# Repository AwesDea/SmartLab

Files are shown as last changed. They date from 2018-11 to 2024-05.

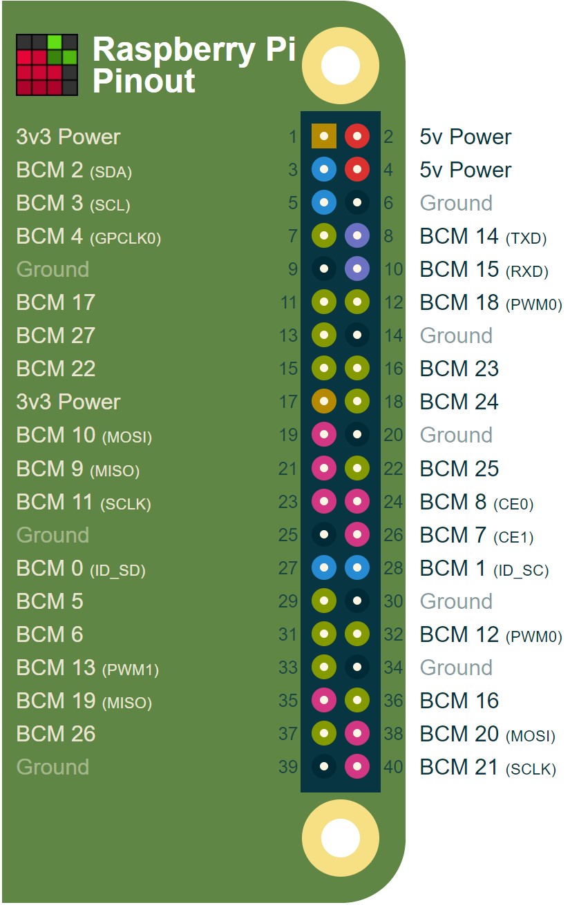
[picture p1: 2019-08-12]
Document/Pic/RPi3 Pinout.jpg

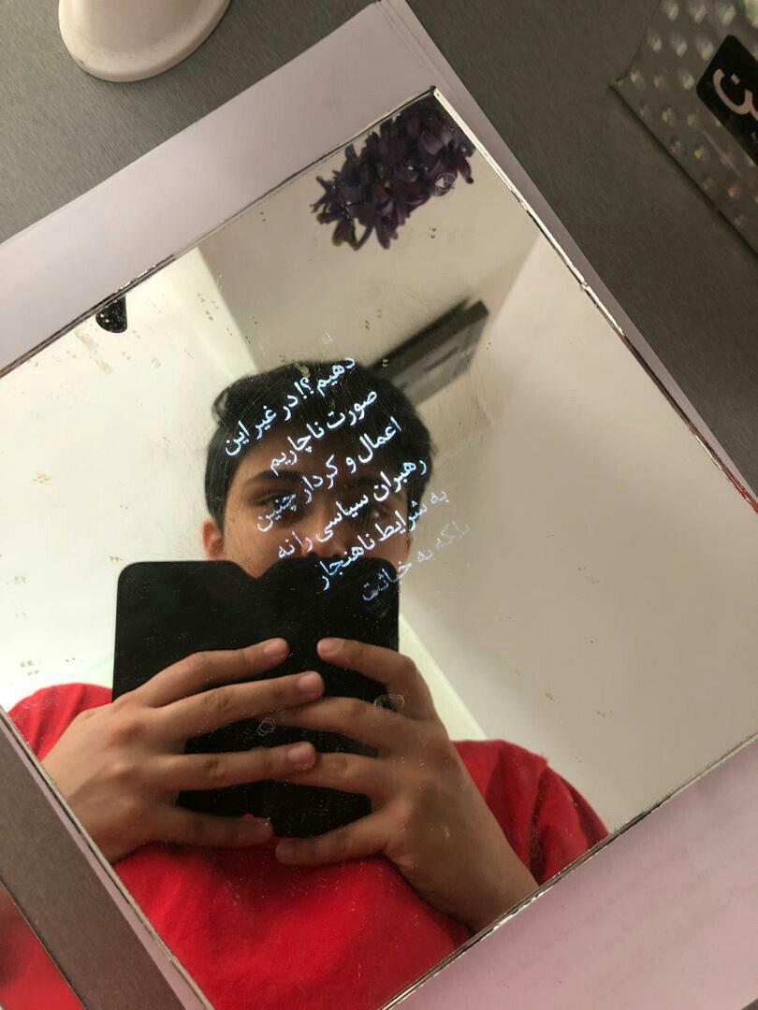
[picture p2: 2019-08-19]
Document/Pic/SMir- Test.jpg

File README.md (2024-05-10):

# Smart Lab with Raspberry Pi and Esp8266

One RaspberryPi, three ESP8266s, a bunch of sensors and data to keep and use it later.

## Built With

* [Python3](https://python.org) - RaspberryPi code
* [Pandas](https://pandas.pydata.org/) - Data Management
* [Arduino Editor](https://www.arduino.cc/) - Used to code and program ESP8266

## Authors

* **Hoorad Abootalebi** - *Most of Hardware work* - [Hoora](https://github.com/HooradAboo)
* **Amin Isaai** - *Most of Software work* - [Amin](https://github.com/HooraAboo)

See also the list of [contributors](https://github.com/your/project/contributors) who participated in this project.

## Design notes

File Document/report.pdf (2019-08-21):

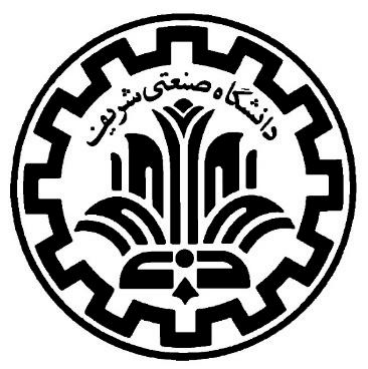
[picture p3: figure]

دانشگاه صنعتی شریف
دانشکدهی مهندسیکامپیوتر

پایاننامهی کارشناسی

عنوان:

## پیاده سازی اتاق هوشمند

نگارش:
فاطمه ابوطالبی، محمد امین عیسایی

استاد راهنما:

علی محمد افشین همتیار

سال تحصیلی ۱۳۹۸-۹۷

به نام خدا
دانشگاه صنعتی شریف
دانشکده مهندسی کامپیوتر

پایان نامه کارشناسی

عنوان: پیادهسازی اتاق هوشمند

نگارش: فاطمه ابوطالبی، محمدامین عیسایی

کمیتهی ممتحنین

استاد راهنما: علی محمد افشین همتیار امضا: تاریخ:

## سپاس

از استاد بزرگوارمان که با کمکها و راهنماییهای بیدریغشان ما را در انجام این پروژه یاری دادهاند، تشکر و قدردانی میکنیم. همچنین از آقای مهندس بهنام بحیرایی که در پیشبرد این مقاله همکاری داشتند، صمیمانه سپاسگزاریم.

## چکیده

با پیشرفت روزافزون تکنولوژی و گسترش حوزهی اینترنت اشیا به منظور ایجاد سهولت در زندگی روزمره، تصمیم گرفتیم با هوشمندسازی محل کار در قسمتی از این پروژهی جهانی سهیم باشیم.

محل کار از بخشهای مختلفی تشکیل میشود که قابلیت هوشمندسازی را دارند. با استفاده از قابلیتها و کمک گرفتن از پروتکلهای ارتباطی از جمله MQTT و دیگر پروتکلهای ارتباطی از راه دور و هم چنین سنسورهای مختلف موجود در بازار تالش خواهیم کرد تا به پیادهسازی محل کاری هوشمند نزدیک شویم و در نهایت بتوانیم محیطی مدرن و پویاتر برای کار ایجاد کنیم و آسایش را برای افراد به ارمغان بیاوریم.

این پروژه در بستر B Model 3 Pi Raspberry انجام میشود. Pi Raspberry
مینیکامپیوتری است دارای چهل پایه، متشکل از بیست و هشت پایهی GPIO و هشت پایهی اتصال به زمین و چهار پایهی VCC است. Pi Raspberry ماژولهای ارتباطی مثل بلوتوث و وایفای، اترنت و ... را به صورت پیشفرض دارا است. همچنین از توزیع مخصوص سیستم عامل لینوکس رPi Raspberry، یعنی رزبین )Raspbian )استفاده خواهیم کرد.

در این پروژه قصد داریم با استفاده از Pi Raspberry و به کمک رابطهای کاربری به پیادهسازی محل کاری هوشمند بپردازیم.

کلید واژه: اینترنت هوشمند، خانهی هوشمند، اتاق هوشمند، IoT، MQTT، Pi Raspberry

## فهرست مطالب

۱5 | Raspberry Pi
24 | ESP8266
2۸ | Arduino
2۸ | Arduino Uno

42 | MQTT

## فهرست شکلها

۱6 | Raspberry Pi 3 Model B 2 شکل

## فهرست جدولها

# مقدمه

۱ | در این فصل در ابتدا تعریفی از اینترنت اشیا

ارائه میشود و سپس به بررسی ساختار، ویژگیها و کاربردهای آن میپردازیم.

## تعریف اینترنت اشیا

اینترنت اشیا شبکهای از دستگاههایی نظیر خودروها و لوازم خانگیای است که قطعات
2 و توانایی ارتباط۳ | الکترونیکی، نرمافزار، عملگرها
همراه خود دارند که به آنها توانایی تعامل و
تبادل داده میدهد ]۱[.

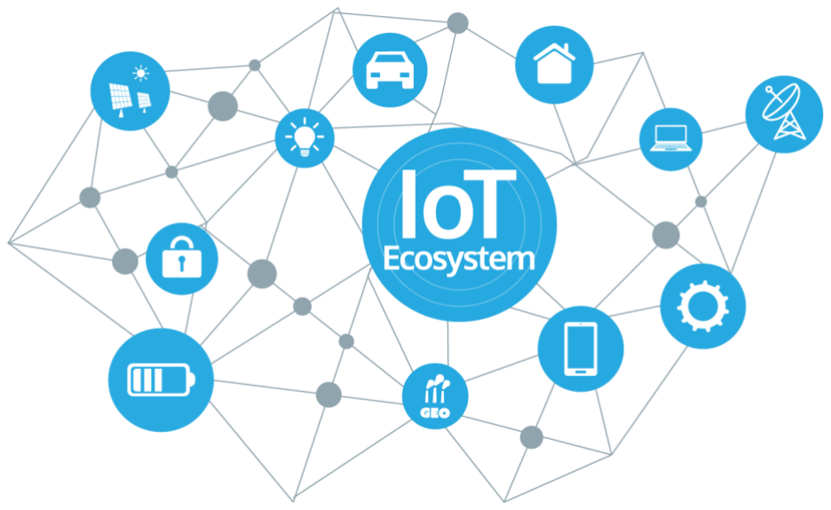
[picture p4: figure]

شکل ۱ اکوسیستم اینترنت اشیا

۱

Internet of Things
2 Actuator

۳ Connectivity

## ساختار اینترنت اشیا

با نگاهی ساده ساختار اینترنت اشیا از سه الیه تشکیل شده است. این سه الیه از قرار زیر هستند:

.۱ الیهی دستگاهها: در این الیه دستگاههایی همانند حسگرها و محرکها که با شبکه به یک
4 | دیگر متصلاند یافت میشوند. معموالً این دستگاهها از قراردادهایی
همچون Modbus و
Zigbee برای ارتباط با الیهی درگاه لبه استفاده میکنند. .2 الیهی درگاه لبه: این الیه از سامانههای جمعاوری دادههای الیهی دستگاهها تشکیل شده است. این الیه عملکردهایی چون پیشپردازش داده، برقراری ارتباط با ابر و در بعضی از
5 | موارد تحلیلهای لبه
6 | و پردازش مه
را ارائه میدهد.
.۳ الیهی ابر: این الیه از برنامه کاربری ابریای که با معماری ریزسرویس

۷

ساخته شده، تشکیل
شده است. این برنامهها به دلیل استفاده از قراردادهایی جون OAuth/HTTP به صورت ذاتی امن هستند و در این الیه پایگاه دادههای فراوانی برای ذخیرهسازی دادههای حسگرها وجود دارند.
از نظر پیچیدگی به خاطر وجود تعداد زیاد لینکهای متفاو، تعامالت و ظرفیت آن برای جای دادن اعضای جدید اینترنت اشیا به عنوان یک سامانهی پیچیده در نظر گرفته میشود.

4 Protocol
5 Edge Analytics

6 Fog Computing
۷ Microservice

## کاربردهای اینترنت اشیا

از میان کاربردهای فراوان اینترنت اشیا کاربردهای اصلی آن شامل خانههای هوشمند، مصارف پزشکی، مصارف صنعتی و مدیریت انرژی میباشد.

- خانههای هوشمند
۸ | دستگاههای اینترنت اشیا بخشی از مفهوم بزرگتر اتوماسیون خانهها
که شامل
۹ | نورپردازی، گرمایش، تهویهی هوا، رسانه و سامانههای امنیتی
است، میباشند. یک خانهی
که دستگاههای هوشمند را کنترل میکند | ۱0 یا قطب۱۱ | هوشمند میتواند بر اساس یک سکو
بنا شده باشد. برای مثال با استفاده از Homekit شرکت Apple، تولدیکنندگان میتوانند محصوالت خود را به گونهای تولید کنند که قادر باشند با یک برنامهی کاربردی در سیستم عامل iOS با استفاده از دستگاهی نظیر iPhone یا Watch Apple کنترل شوند.
- مصارف پزشکی
دستگاههای اینترنت اشیا زیر نظرگیری سالمت از راه دور و سامانههای اعالن اضطراری
را ممکن میسازند. دستگاههای زیر نظرگیری سالمت شامل بازه بزرگی از دستگاههای ساده و کوچکی نظیر اندازهگیری فشار خون و ضربان قلب تا دستگاههای پیشرفتهای با
باشد. ۱2 | قابلیت زیر نظرگیری ایمپلنتهای مخصوص نظیر قلب مصنوعی
- مصارف صنعتی

۸ Home Automation
۹ Security System
۱0 Platform

۱۱ Hub
۱2 Pacemaker

اینترنت اشیا میتواند امکان یکپارچهسازی دستگاههای تولیدی مختلفی که دارای
گر، محرک و ارتباط را محقق کند ]2[. | ،۱۳ پردازش | دستگاههای حسگر، تشخیصدهنده
- مدیریت انرژی
شمار زیادی از دستگاههای پرمصرف قابلیت اتصال به اینترنت را دارند که آنها را قادر میسازد با مراکز تأمین حاملهای انرژی در ارتباط باشند تا تولید و مصرف انرژی برای یک سامانه بزرگ مدیریت شود. این دستگاههای اجازه کنترل راه دور توسط کاربر یا
را میدهند و عملکردهایی نظیر برنامهریزی را ممکن | ۱4 | کنترل مرکزی با رابط بر پایهی ابر
میسازند.
۱۳ Identification | ۱4 Cloud-Based Interface

# ریزکنترلکنندهها

استفاده | ۱۷ | با کاربردی خاص هستند که در سیستمهای نهان | ۱6 | مدارهای مجتع | ۱5 | ریزکنترلکنندهها
میشوند. معموالً ریزکنترلکنندهها از پردازنده، حافظه و لوازم جانبی
۱۸

تشکیل شدهاند ]۳[.

در ادامه به توضیح بیشتر در خصوص دو ریزکنترلکنندهی Pi Raspberry و 8266ESP که در این پروژه استفاده شدهاند، میپردازیم.

Raspberry Pi
Pi Raspberry یک رایانه تک برد در اندازه یک کارت اعتباری است که بنیاد
Pi Raspberry آن را ساختهاست تاآموزش علومرایانهرادرمدرسهها تشویق کند ]4[. سهنسخه از این رایانه ساخته شده که قیمت نسخههای اول و دوم به ترتیب 25 و ۳5 دالر امریکا )به عالوهی مالیات محلی( و نسخه سوم آن با نام zero تنها 5 دالر است.

این رایانه دارای دیسک سخت نیست ولی به کمک حافظه SD، خود را راه اندازی میکند. این رایانه قادر است با سیستم عاملهای مختلفی راه اندازی شود. سیستم عامل اولیهای که با آن عرضه شد لینوکس نسخه Debian بود اما امروزه نسخههایی از اندروید، ویندوز و ... نیز برای آن تهیه شده است. این رایانه با کمک یک کابل USB Micro تغذیه میشود. Pi Raspberry قادر است به کمک یک کابل تصویر ویدئو و یک درگاه سوزنی، خروجی صدا و تصویر داشته و یا با کابل HDMI، خروجی تصویری بادقت ویدیوی HD و صدایی استریو داشتهباشد. دودرگاه USB نیز برای آن در نظر گرفته شده است که میتوان از آن برای ارتباطات مختلف استفاده کرد. از

۱5 Microcontroller
۱6 Integrated Circuit

۱۷ Embedded System
۱۸ I/O Peripheral

خروجی های USB برای صفحه کلید، ماوس، شبکه بیسیم و کلیه دستگاههای مورد استفاده از درگاه فوق بهره برده میشود. به کمک هاب USB میتوان از پورت های بیشتری استفاده کرد. نسخه B این رایانه یک خروجی شبکه نیز دارد که به کمک آن میتوان به شبکه های محلی و یا اینترنت متصل شد. از خروجی HDMI برای صدا، تصویر و کنترل آن با هم میتوان بهره جست .]5[

در این پروژه از B Model 3 Pi Raspberry استفاده خواهد شد. )شکل 2(

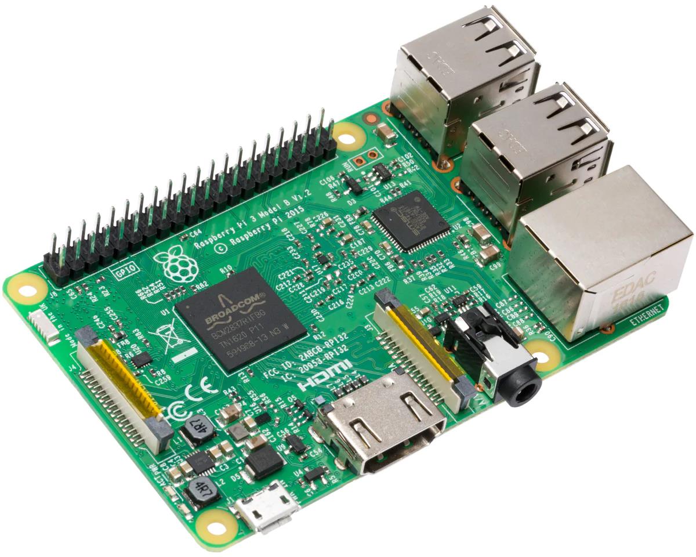
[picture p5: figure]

Raspberry Pi 3 Model B 2 شکل

سختافزار
نسلهای متفاوتی از Pi Raspberry تا به امروز عرضه شده است که تمامی این مدلها دارای
20 | شامل دو بخش پردازنده و پردازندهی گرافیکی | ۱۹ | یک SoC
هستند ]6[.
تازگی | به و Raspberry Pi 2 ،Raspberry Pi Model A/A+ | مدلهای | امروز | تابه
Zero Pi Raspberry معرفی شده است. در جدول۱ به جزئیات هر مدل پرداخته شده است ]۷[.

پین های این مینی کامپیوتر در شکل ۳ معرفی شدهاند ]۸[.

۱۹ System on a Chip | 20 Graphic Process Unit (GPU)

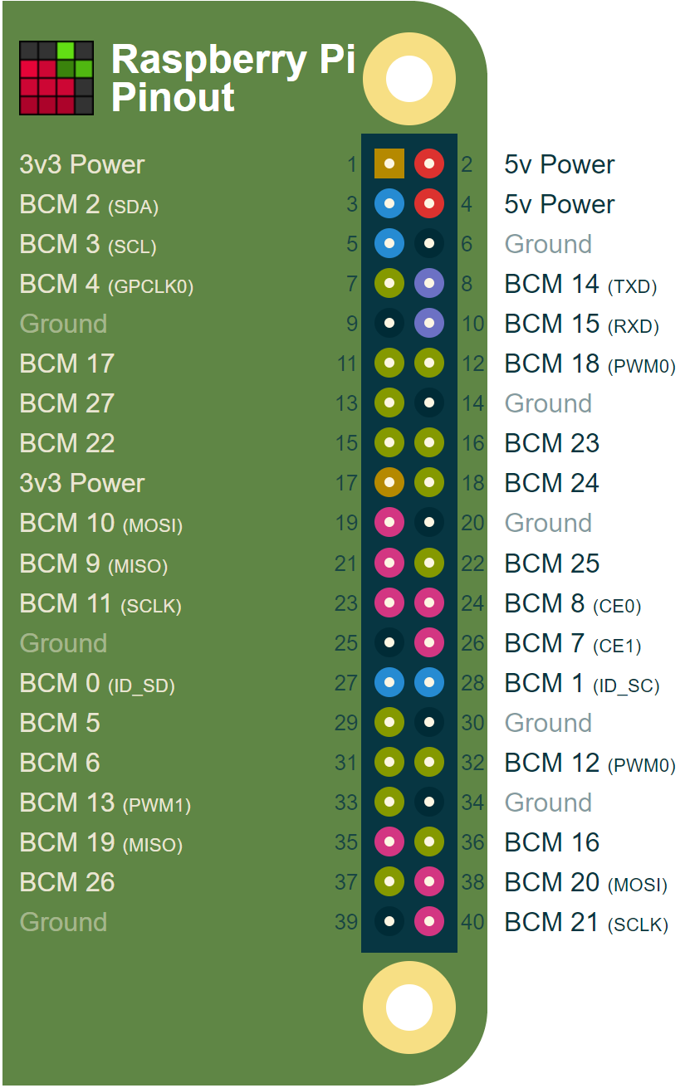
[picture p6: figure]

شکل ۳ پینهای خروجی 3 Pi Raspberry

Column1 | Raspberry Pi 3 Model A+ | Raspberry Pi 3 B+ | Raspberry Pi Zero WH | Raspberry Pi Zero W | Raspberry Pi 3 | Raspberry Pi Zero | Raspberry Pi 2 | Raspberry Pi A+ | Raspberry Pi B
Release date | 2018 Nov 15 | 2018 Mar 14 | 2018 Jan 12 | 2017 Feb 28 | 2016 Feb 29 | 2015 Nov 30 | 2015 Feb 1 | 2014 Nov 10 | 2012 Feb 15
Price (US$) | 25 | $35 | 15 | 10 | 35 | 5 | 35 | 20 | 39.95
SOC Type | Broadcom BCM2837B0 | Broadcom BCM2837B0 | Broadcom BCM2835 | Broadcom BCM2835 | Broadcom BCM2837 | Broadcom BCM2835 | Broadcom BCM2836 | Broadcom BCM2835 | Broadcom BCM2835
Core Type | Cortex-A53 64-bit | Cortex-A53 64-bit | ARM1176JZF-S | ARM1176JZF-S | Cortex-A53 64-bit | ARM1176JZF-S | Cortex-A7 | ARM1176JZF-S | ARM1176JZF-S
No. Of Cores | 4 | 4 | 1 | 1 | 4 | 1 | 4 | 1 | 1
GPU | VideoCore IV | VideoCore IV | VideoCore IV | VideoCore IV | VideoCore IV 1080p@30 | VideoCore IV | VideoCore IV | VideoCore IV | VideoCore IV 1080p@30
CPU Clock | 1.4 GHz | 1.4 GHz | 1 GHz | 1 GHz | 1.2 GHz | 1 GHz | 900 MHz | 700 MHz | 700 MHz
RAM | 512 MB DDR2 | 1 GB DDR2 | 512 MB | 512 MB | 1 GB DDR2 | 512 MB | 1 GB | 256 MB | 512 MB
USB Ports | 1xUSB 2.0 | 4xUSB 2.0 | micro & micro OTG | micro & micro OTG | Yes 4 | micro & micro OTG | 4 | Yes 1 | - 2
Power sources Ethernet | microUSB or GPIO No | microUSB or GPIO Yes | microUSB or GPIO No | microUSB or GPIO No | microUSB or GPIO Yes | microUSB or GPIO No | microUSB or GPIO Yes | microUSB or GPIO No | microUSB or GPIO SOC Wired Connectivity Wireless Connectivity Dimensions Power Details Yes
SATA Ports | No | No | No | No | No | No | No | No | No
HDMI port | Yes | Yes | Yes | Yes | Yes | Yes | Yes | Yes | Yes
Analog Video Out | Yes | Yes | Yes | Yes | Yes | Yes | Yes | Yes | Yes
Analog Audio Out | Yes | Yes | Yes | Yes | Yes | Yes | Yes | Yes | Yes
SPI | Yes | Yes | Yes | Yes | Yes | Yes | Yes | Yes | Yes
I2C | Yes | Yes | Yes | Yes | Yes | Yes | Yes | Yes | Yes
GPIO | Yes 40-pin | Yes 40-pin | Yes | Yes | Yes 40-pin | Yes | Yes | Yes | - 26-pins
LCD Panel | Yes | Yes | No | No | Yes | No | Yes | Yes | Yes
Camera | Yes | Yes | Yes | Yes | Yes | Yes | Yes | Yes | Yes
SD/MMC | Yes | Yes | Yes | Yes | Yes | Yes | Yes | Yes | Yes (SD)
Wi-Fi | Yes | Yes | Yes | Yes | Yes | No | No | No | No
Bluetooth® | Yes 4.2, BLE | Yes 4.2, BLE | Yes 4.1 | Yes 4.1 | Yes 4.1 LE | No | No | No | No
Height | 65 mm | 85.6 mm | 30 | 30 | 85.6 | 30 | 85.6 | 65 | 53.98
Width | 56 mm | 56.5 mm | 65 | 65 | 56.5 | 65 | 56.5 | 56.5 | 85.6
Depth | 11 mm | 0.66929 in (17 mm) | 13 | 5 | 17 | 5 | 17 | 10 | 17
Weight | 29 g | 1.58 oz (45 g) | 12 | 9 | 45 | 9 | 45 | 23 | 45
Power ratings | | 1.13 A @5V | 180 mA | 180 mA | 1.34 A @5V | 160 mA | 800 mA | 200 mA | 700 mA @5V

جدول ۱ مقایسهی مدلهای متفاوت Pi Raspberry

سیستم عامل
بردهای Pi Raspberry توانایی اجرای سیستم عاملهای مختلفی را دارند. در اکثر سیستم عاملهای لینوکسی برای Pi Raspberry میتوانید دسکتاپ و دسترسی را تغییر دهید. دانستن این سیستم عاملها به قدرت انتخاب کاربران بر اساس نیاز و استفادهشان کمک خواهد کرد.

در این بخش انواع سیستمعاملهایی که به صورت رسمی توسط بنیاد Pi Raspberry و غیر رسمی معرفی شده اند را بررسی خواهیم کرد ]۹[.

Raspbian
Raspbian سیستمعاملی رایگان و بر پایهی لینوکس Debian است. این سیستم عامل توسط بنیاد Pi Raspberry (https://daneshjookit.com/108-%D8%B1%D8%B2%D8%A8%D8%B1%DB%8C-%D9%BE%D8%A7%DB%8C-raspberry-pi) توسعه داده شده است. سیستم عامل Raspbian بهترین و بیشترین انتخاب کاربران است. سرعت پاسخ گویی و کارایی سیستم عامل بسیار عالی است. Raspbian از دسکتاپ سبک و کمحجم Xfce استفاده میکند. حجم این سیستم عامل حدود 4 گیگابایت است.

در این پروژه از این سیستمعامل استفاده خواهیم کرد.

Google Coder
این سیستمعامل به صورت رسمی از سوی گوگل ارائه شده است. با سیستمعامل Google

Coder برد Pi Raspberry به یک سرور جهت برنامهنویسی HTML ، CSS، Script Java و
NodeJSتبدیل میشود. قابلیت مدیریت فایلهای هر پروژه و Preview Live نیز در این سیستمعامل وجود دارد.

Android
سیستم عامل اندروید مخصوص برد Pi Raspberry توسط یکی از توسعهدهندگان به صورت غیر رسمی ارائه شده است. آخرین نسخه آن اندروید ۷ Noughat است. حجم این سیستم عامل حدود 400 مگابایت است. تقریباً از تمامی قابلیتهای اندروید میتوان در برد Pi Raspberry استفاده کرد. ولی سرعت و عملکرد آن نسبت به دیگر سیستمهای عامل پایینتر است.

Chromium OS
سیستمعامل کرومیوم توسط گوگل Pi Raspberry ارائه شده است. البتهبهصورت غیررسمی برای Pi Raspberry پورت شده است. حجم آن حدود ۱ گیگابایت است. بهترین کاربرد این سیستمعامل سبک، وبگردی است.

Ubuntu Mate
سیستمعامل اوبونتو توزیعهای مختلفی دارد. Mate Ubuntu نسخه دسکتاپ دارد. این نسخه بسیار سبک است. نسخه Mate Ubuntu مخصوص برد Pi Raspberry دقیقا همانند نسخه دسکتاپ است. Mate Ubuntu بر پایهی Ubuntu بوده و حجم آن ۸ گیگابایت میباشد. در مقایسه با سیستم عامل رزبین سرعت آن کمی کُند است. ولی جامعه کاربری تمام تالشش را برای بهینه سازی انجام داده است.

RaspBMC
سیستم عامل گنو/لینوکسی RaspBMC، برای تبدیل Pi Raspberry بهیکمدیاسنتر خانگی ساخته شده است. کافیست پس از نصب سیستم عامل RaspBMC برد را به تلوزیون وصل کنید. از برخی از قابلیتهای این سیستم عامل میتوان به پشتیبانی از زیرنویس فارسی، پشتیبانی از اکثر فرمتهای ویدئویی، پشتیبانی از فیلمهای با وضوح ۱0۸0p و پشتیبانی از تماشای ویدئو به صورت آنالین اشاره کرد.

Retropie
این سیستمعامل بهترین سیستمعامل برای تبدیل Pi Raspberry به یک کنسول بازی کامل میباشد. این سیستمعامل نیز بر پایهی دبیان است و آخرین نسخه از آن حدود 2 گیگابایت حجم
کار میکند؛ حتی از دستههای | 2۱ | دارد. Retropie به صورت پیشفرض با دستههای بازی

2۱ Joystick

Playstation و Xbox نیز پشتیبانی میکند. پکیجهای مختلفی از شبیهسازهای بازی بر روی Retropie قابل نصب هستند. بازیهای قدیمیای مانند Doom، Warcraft، Nuke Duke و ... نیزبه صورت پورت شده بر روی این سیستمعامل قابل اجرا میباشند.

Lakka
این سیستمعامل مانند Retropie بوده؛ اما با قابلیتها و حجم کمتر. سرعت رابط کاربری آن نیز کمی از Retropie بیشتر است. حجم آن حدود ۱40 مگابایت میباشد. الکا فقط از کنسولهای معروف مانند 1 Station Play و PSP پشتیبانی میکند.

RISC OS Open
سیستم عامل OS RISC مخصوص پردازندههای ARM طراحی شده است. این سیستم عامل برپایه هیچ یک از سیستم عاملهای لینوکس و یونیکس نمیباشد.

Windows 10 IoT Core
سیستم عامل Core IoTروی برد Pi Raspberry و Max Minnowboard قابل اجراست.
سیستم عامل ویندوز IOT روی دستگاههای بدون نمایشگر هم کار کند. از آنجایی که Core IoT نسخه کم حجم شده ویندوز ۱0 است؛ در آن رابط کاربری پنجرهای و دسکتاپ را نمیبینید. بلکه توسعه دهندگان باید اپلیکیشن فراگیر را پیاده سازی نمایند که نقش رابط کاربری را عهده دار شود.

PiNet
سیستم عامل پای نت با نگرش استفاده در کالسهای درس طراحی شده است. یک Pi Raspberry به عنوان سیستم مرکزی با سیستم عامل پای نت PiNet به عنوان سیستم مرکزی و دیگر بردهای Pi Raspberry در کالس درس به آن متصل میشوند. هر دانش آموز دارای نام کاربری و گذر واژه خواهد بود. با این روش فعالیتهای کلیه دانش آموزان قابل ردیابی است. همچنین طراحی سیستم عامل پای نت PiNet کال از کف انجام شد است. از این رو تمامی نکات مورد نیاز در کالس درس در آن اعمال شده است.

Noobs
پیشنهاد بنیاد Pi Raspberry برای تازه کارها استفاده از سیستم عامل نوبز Noobs است. این سیستم عامل سبک و سریع است. نوبز Noobs مخفف Software Box Of Out New میباشد. نصب نوبز بسیار ساده است و پس از نصب آن میتوان عاملهای مورد نظر را از لیست انتخاب کرد تا خودشان اتوماتیک نصب شوند. به عبارتی یک رابط برای نصب سیستم عاملهای دیگر است.

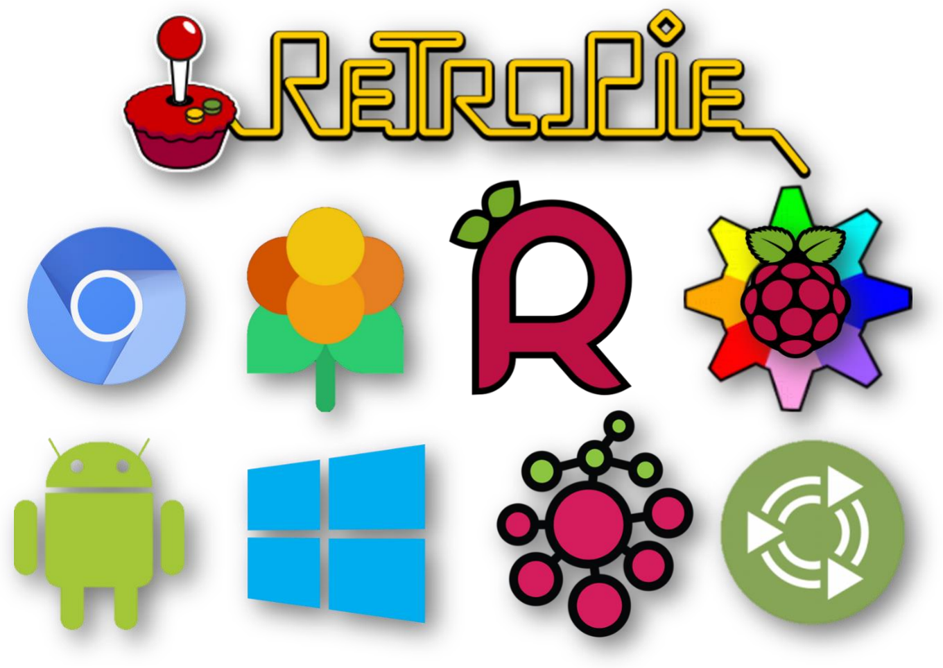
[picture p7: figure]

شکل 4 لوگوی برخی از سیستمعاملهای مخصوص Pi Raspberry

ESP8266
ESPها میکروکنترلرهای کوچک و ارزان قیمتی هستند که میتوانند به شبکهی Fi-Wi وصل شده و به راحتی ارتباطی از جنس IP/TCP برقرار کنند. با استفاده از این ماژول به راحتی میتوان دستگاههای الکترویکی را از راه دور و از طریق اینترنت کنترل کرد. این ماژولها توان مصرفی کمی دارند.

ماژولهای ESP انواع متفاوتی دارند که تمامی آنها از یک پردازندهی یکسان استفاده میکنند
و تفاوت اصلیشان در تعداد پایههای در دسترس است. هر نوع فواید و مضراتی دارد که بسته به هدف پروژه باید انتخاب شود. در این پروژه از ماژول 8266-01ESP استفاده شده است.

این نوع ESP یکی از پر استفادهترین انواع ESP است که البته کار با آن به سادگی دیگر انواع
آن نیست. این نوع ESP ابعاد کوچکی داشته و به نسبت دیگر مدلها ارزانتر است. دارای ۸ پایه بوده )شکل 5( و به راحتی در بازار ایران یافت میشود.

در این پروژه قصد داریم با استفاده از یک مودم و پروتکل MQTT اطالعات را از
منتقل کرده و ESP از شبکه دریافت کرده و اطالعات را از | 22 | Pi Raspberry به شبکهی محلی
طریق GPIO به دستگاه متصل به آن میدهد. )دقت شود که این پروژه مبنی بر شبکهی محلی است و از اینترنت استفادهای نمیکند(.

در این پرژه از سه 8266-01ESP استفاده میشود. ESP اول مربوط به کنترل نور، ESP دوم مربوط به سیستم تهویه و خنک کننده و آخرین ESP نیز برای بررسی آلودگی ودمای هوای داخل اتاق استفاده میشود.

22 Local Network

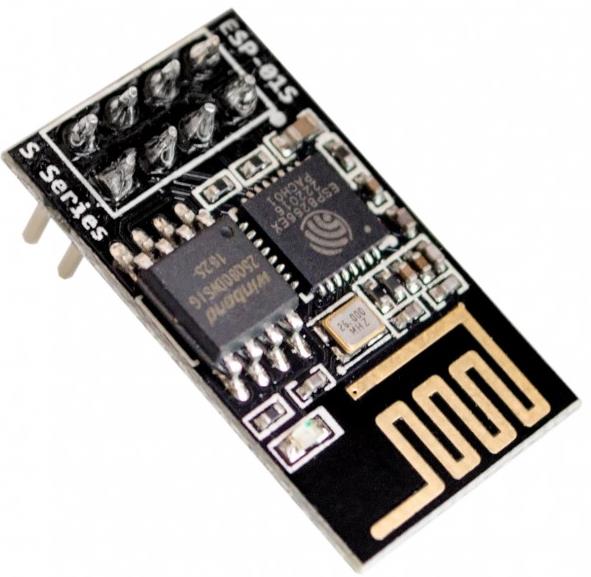
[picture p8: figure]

شکل 5 ماژول 8266-01ESP
برنامهریزی
ESPها با استفاده از روشهای متفاوتی قابل برنامهریزی هستند که راحتترین روش آن استفاده از مبدل USB به TTL( شکل 6( است.

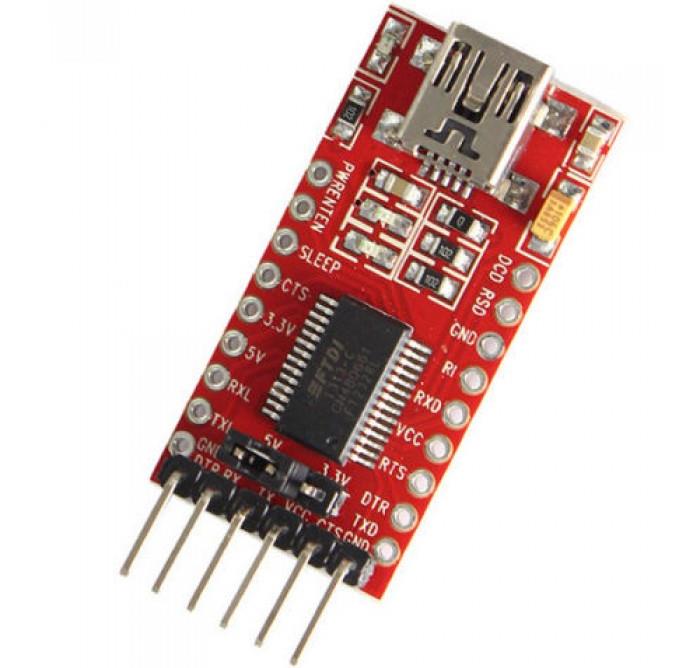
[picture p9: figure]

شکل 6 مبدل USB به TTL

مبدل USB به سریال، ابزاری است که برای ارسال و دریافت دادهها از یک رابط UART مورد استفاده قرار میگیرد. این مبدل به برنامهنویسی برای میکروکنترلرها ندارد و قابلیت ارسال و دریافت دادهها را بین ماژول های UART مانند ,GPS ,GSM بلوتوث، Fi-Wi و ... و همچنین کامپیوتر از طریق پورت USB را دارد. با استفاده از مبدل USB به سریال ، به راحتی میتوانید پروژه یا محصول خود را به رابط USB مجهز کنید. این مبدل، امکان برقراری ارتباط با کامپیوتر از طریق پورت USB را فراهم میکند. در حقیقت با اتصال این مبدل به کامپیوتر و نصب برنامه درایور، یک پورت سریال مجازی به پورتهای کامپیوتر افزوده میشود. این مبدل قابلیت کار با سیستم عاملهای متفاوت را دارا میباشد. با استفاده از این ماژول بردهایی که فاقد پورت USB هستند را به راحتی میتوان برنامهریزی کرد.

برای اتصال 8266-01ESP به مبدل کافی است به شیوهای که در ادامه گفته شدهاست میتوان عمل کرد )جدول 2 و شکل ۷(

هنگامی که ESP در حالی روشن شود که پایهی 0GPIO آن به زمین وصل باشد، ESP به حالت برنامهریزی شدن رفته و آمادهی نوشتن روی حافظهی خود میشود. پس حتماً دقت شود که قبل از اتصال پایهی VCC به ولتاژ v،3.3 پایهی 0GPIO به زمین وصل شده باشد.

دقت شود که بیشتر از v3.3 به ESP نباید ولتاژ داده شود. پس ولتاژ مبدل حتماً باید روی v3.3 تنظیم شود.

استفاده نمیکنید، پایهی Reset را مستقیماً به VCC وصل کنید. | 2۳ | در صورتی که از دکمه

2۳ Button

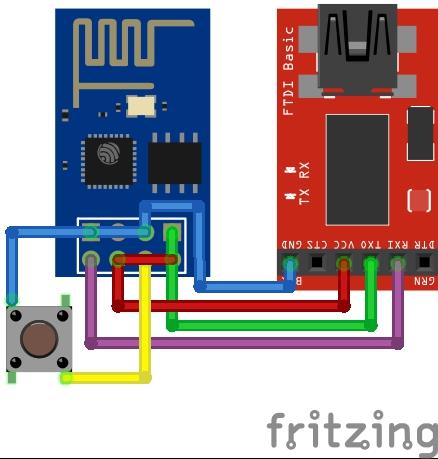
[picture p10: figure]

شکل ۷ شماتیک مدار برنامهریز مخصوص 8266-01ESP

ESP8266-01 | USB-to-TTL Converter | جدول 2 نحوهی اتصال
TX | RX | 8266-01ESP به مبدل -USB
GND | GND
CH_PD | VCC
GPIO2 | -
RST | Button
GPIO0 | GND
VCC | VCC
RX | TX
GPIO2 | RX

to_TTL

معماری
است. ESPها توان مصرفی بسیار کمی | 24 | این میکروکنترلر ۳2 بیتی بوده و معماری آن RISC
دارند و بیشترین مقدار کالک آنها به MHz 160 میرسد. همچنین دارای MiB 1 حافظهی Flash و KiB32 حافظه مختص دستورات

میباشد. 25

Arduino
. پلتفرم Arduino شامل یک | 26 است | Arduino یک پلتفرم سختافزاری و نرمافزاری متنباز
که قسمت سختافزار Arduino را تشکیل میدهد. عالوه بر این | 2۷ است | ریزپردازندهی تکبردی
یک IDE به منظور برنامهنویسی برای بردهای Arduino طراحی شدهاست. پلتفرم Arduino به منظورتولید سریع و ساده پروژههای سختافزاری تعاملی و ساخت وسایلی کهبا محیطتعامل داشته باشند طراحی شدهاست. البته بردهای Arduino اهداف آموزشی را نیزدنبال میکنند.

اغلب بردهای Arduino که تمام آنها سختافزار متنباز هستند بر پایه ریزپردازندهی AVR Atmel وتعداد کمی ازبردهایArduino برپایهریزپردازندههای Atmel ARM طراحی شدهاند.

Arduino Uno
برد Uno Arduino که پرکاربردترین برد Arduino و برد پایه Arduino در اکثر دورههای آموزش Arduino است وبرپایهمیکروکنترلر 328ATmega AVR ساخته شدهاست،دارای رابط یواسبی جهت بارگذاری برنامه و ارتباط با کامپیوتر، 6 پین ورودی آنالوگ و همچنین ۱4 پین ورودی/خروجی دیجیتال است که شما را قادر میسازند تا برد Arduino را به قطعات، سنسورها،

24 Reduced Instruction Set Computer

25 Instruction RAM

26 Open Source
2۷ Single Board

بردهاوماژولهای دیگری متصل کنید. تعدادورودی خروجیهای آنالوگ ودیجیتال درمدلهای مختلف بردهای Arduino با توجه به میکروکنترلر اصلی استفاده شده بر روی برد متفاوت است.

در این پروژه در بخشی از بخشها مخصوصاً برای تست ماژولها و یادگیری کار با آنها از این برد استفاده کردیم. )شکل ۸(

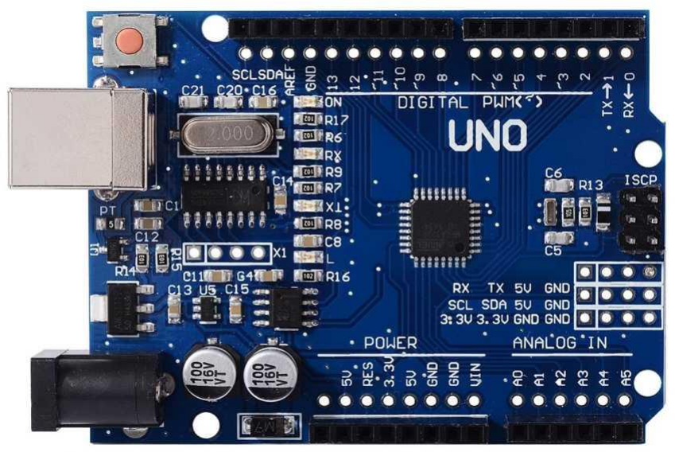
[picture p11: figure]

شکل ۸ برد Arduino مدل Uno

# آینهی هوشمند

در این پروژه از یک آینهی هوشمند به عنوان صفحه نمایشگر پروژه استفاده خواهیم کرد.

آینهی هوشمند آینهای است که عالوه بر نشان دادن تصویر شما، قابلیت نمایش اطالعاتی نظیر زمان، آب و هوا، تاریخ و ... را همزمان با بازتاب تصویر را داراست.

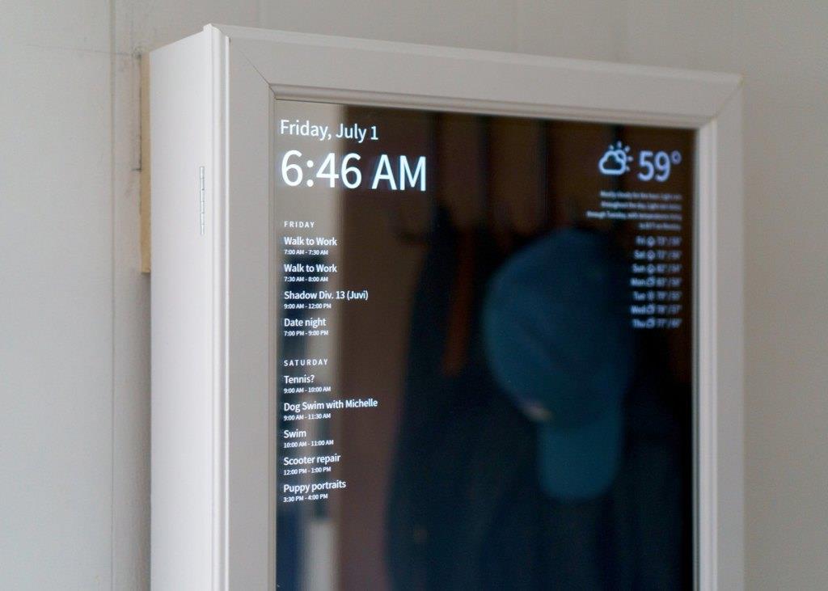
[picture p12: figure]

شکل ۹ نمونهای از یک آینهی هوشمند

## ساختار

2۸ | برای ساخت این آینهها به یک آینهی یک طرفه

، یک صفحهی نمایشگر در پشت آینه و
یک ریزپردازنده نیاز است؛ که در این پروژه از Pi Raspberry استفاده شده است.

آینههای یک طرفه آینههایی هستند که یک طرف آن نور را از خود عبور داده و طرف دیگر نور را بازتاب میکند. این آینهها با نامهای شیشهی یکطرفه و آینههای دو طرفه نیز یافت میشوند. )شکل ۹(

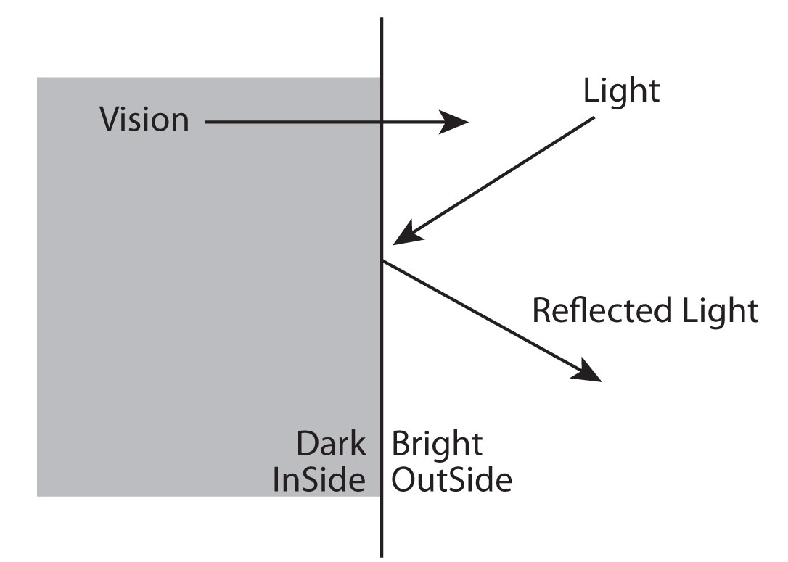
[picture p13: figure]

شکل ۱0 نحوهی بازتاب نور در شیشههای یک طرفه

2۸ One-Way Mirror

با توجه به توضیحی که در خصوص این نوع آینه داده شد، از هر ابزار دیگری مانند شیشههای کوتینگ آلومینیوم یا کروم، پلکسیهای یکطرفه و ... که همچین خاصیتی داشته باشد نیز میتوان استفاده کرد. از آن رو که تهیهی چنین آینهای هزینهبر بود؛ به ساخت یک آینهی یک طرفه پرداختیم؛ که در ادامه بیشتر توضیح داده خواهد شد.

## ساخت آینهی یک طرفه

برای این کار ابتدا باید با استفاده از تینر بخش رنگی پشت آینه را به آرامی سابید. سپس با یک سمبادهی بسیار نرم اندکی از ضخامت جیوهی پشت آینه را کم کرد تا نور بتواند از آن عبور کند.

حال با انداختن تصویری سفید با پس زمینهای سیاه بر روی نمایشگر و قرار دادن آن در پشت آینه میتوان تغییر به وجود آمده را مشاهده کرد.

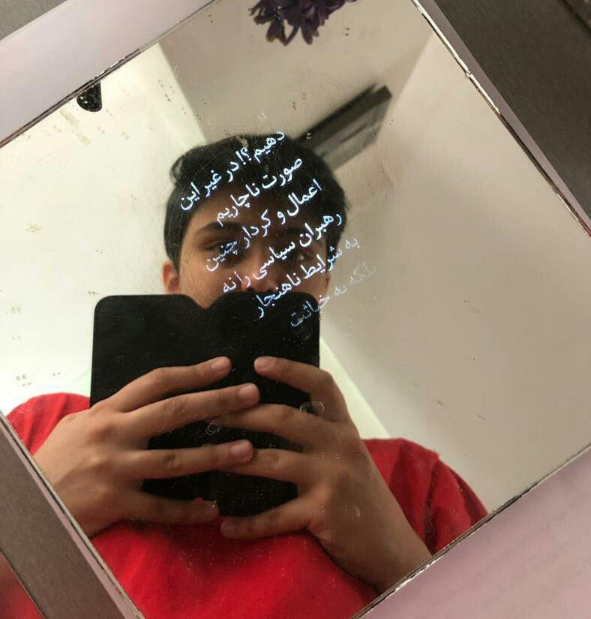
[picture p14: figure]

شکل ۱۱ نمونهی اولیه از ساخت آینهی یک طرفه

# سنسورها

## دوربین

برای تشخیص چهرهی افراد توسط آینهی هوشمند به منظور ورود به حساب کاربری فرد، نیاز به یک دوربین میباشد. در این پروژه از دوربین مخصوص Pi Raspberry استفاده شده است.

این دوربین 5 مگاپیکسل بوده و به راحتی با کابل فلت به پایهی مخصوصی به Raspberry Pi متصل میشود. )شکل ۱2(

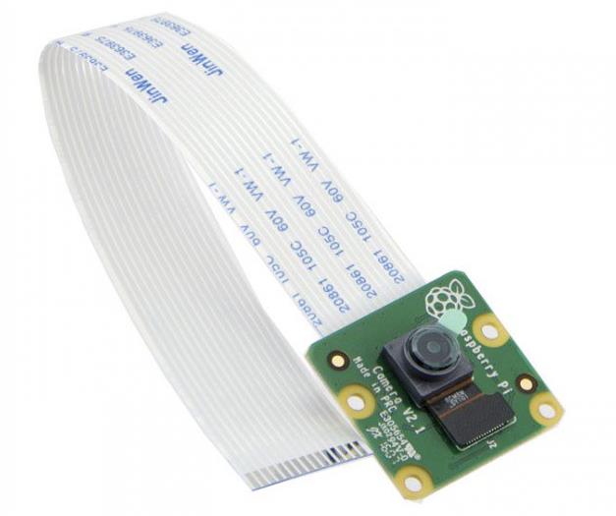
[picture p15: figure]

شکل ۱2 دوربین Pi Raspberry

## کارتخوان

تراشه 522RC MF برای خواندن و نوشتن غیر تماسی تگهای RFID در فرکانس 13.56 MHz به کار میرود. راه اندازی با ولتاژ پایین، قیمت کم،انداز کوچک ارتباط بدون تماس چیپ برای خواندن و نوشتن روی کارت و انتقال دو طرفه دیتا با سرعت s/kb 424 این چیپ را برای دستگاههای هوشمند و قابل حمل مناسب ساخته است. ماژول 522RC دارای قابلیت استفاده آسان با بردهای Arduino و کاربری مناسب در توسعه ی تجهیزات و کارت خوانهای RF میباشد. این ماژول از یک مودالسیون برجسته و دمدوله کردن کامال یک پارچه برای ارتباط بدون تماس در محدوده فرکانسی MHz 13.56 بهره میگیرد. این ماژول میتواند به طور مستقیم در قالبهای مختلف ریدر به کار رود ]۱0[.

ولتاژ V،3.3 جریان مصرفی mA ،13-26 ارتباط از طریق رابط SPI و سرعت انتقال داده 10 s/Mb از مشخصات این ماژول است. ارتباط برقرار شده توسط این ماژول پایدار و قابل اطمینان است ]۱0[.

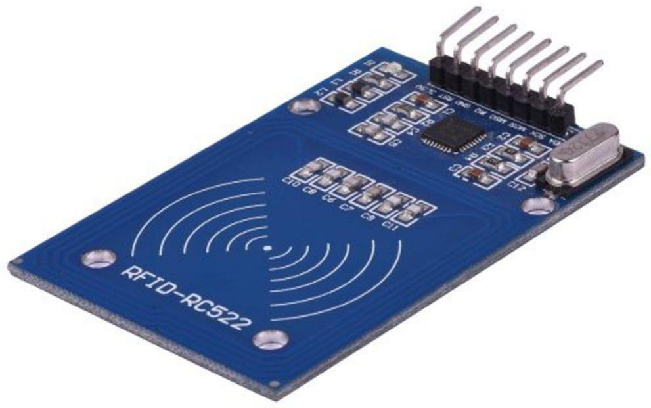
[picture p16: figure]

شکل ۱۳ ماژول کارتخوان

## مادون قرمز

سنسورهای IR یا مادون قرمز سنسورهای کوچکی هستند که مقدار موج مادون قرمزی که از شی رو به رویشان تابش میشود را میتوانند بسنجند. )شکل ۱4(

شکل ۱4 ماژول گیرندهی مادون قرمز
از این سنسور در کنار تمامی ریزپردازندههای 8266ESP قرار گرفته است تا عالوه بر تنظیم خودکار سیستم، کاربر بتواند به صورت دستی با استفاده از یک ریموت کنترل نیز خانهی خود را اداره کند.

## کنترل از راه دور

وسایلی هستند که با استفاده از یک سنسور فرستندهی IR استفاده | 2۹ | کنترلهای از راه دور
میکنند و الگویی از موج مادون قرمز را میفرستند. گیرنده با دریافت موج و رمزگشایی آن اطالعات ارسالی را میکند. )شکل۱5(

2۹ Remote Control

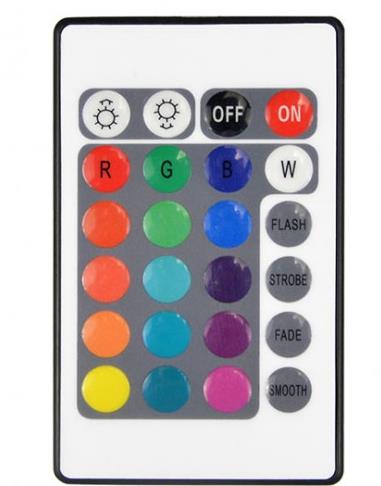
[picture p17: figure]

شکل ۱5 کنترل از راه دور
از این نوع کنترل که در شکل ۱5 مشاهده میشود، عموماً برای سیستمهای روشنایی استفاده میشود. در این پروژه برای استفاده از این کنترل ابتدا یک مدار )شکل ۱6( برای یافتن کد ارسالی توسط هر دکمه از کنترل طراحی شد.

برای ساخت مدار تشخیص دهندهی کد IR تنها کافی است که یک گیرندهی IR را به یکی از پایههای آنالوگ Arduino وصل کنیم و این مقدار را در مبنای ۱6 در سریال IDE Arduino مشاهده کنیم. نتایج به دست آمده در جدول ۳ قابل مشاهده است.

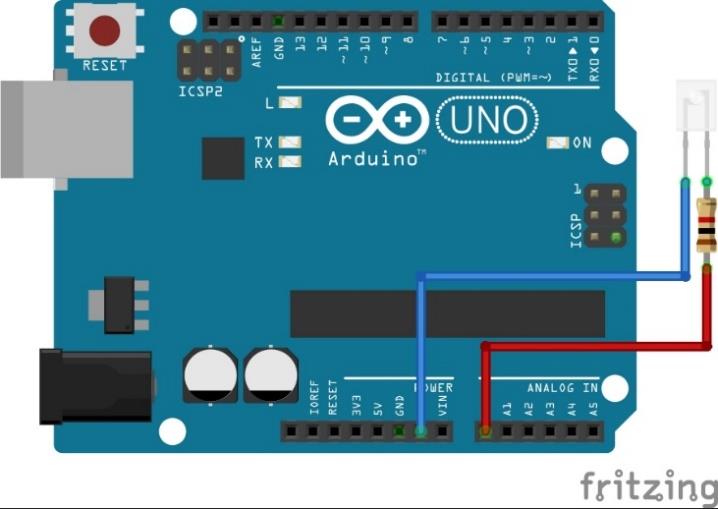
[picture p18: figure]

شکل ۱6 مدار رمزگشای IR

جدول ۳ کدهای خروجی هر یک از دکمههای کنترل

## سنجش دما و رطوبت

سنسور رطوبت 11DHT( شکل ۱۷(، یک سنسور ارزان قیمت جهت سنجش دما و رطوبت هواست که به راحتی میتواند به برد Arduino و یا سایر میکروکنترلرها متصل گردد. اندازه کوچک این سنسور، مصرف کم انرژی و انتقال سیگنال به مسافتی بیش از 20 متر، آن را به یکی از بهترین گزینهها جهت استفاده در پروژههای مختلف، بدل کرده است ]۱۱[.

البته، نوع دیگری از سنسورهای تشخیص رطوبت و دمای سری DHT به نام 22DHT نیز موجود میباشد که نسبت به مدل 11DHT دقیقترو البته گرانتراست.

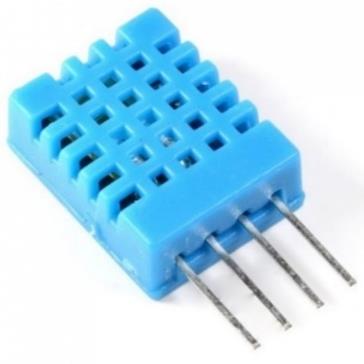
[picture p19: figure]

شکل ۱۷ سنسور تشخیص دما و رطوبت 11DHT

Button | HEX Code | Button | HEX Code
UP | 8503705D | 5 | 14789DB9
DOWN | DEB0C861 | 6 | F7708F
OFF | D4DD0381 | 7 | F708F7
ON | F7C03F | 8 | F78877
R | E85952E1 | 9 | 6A844445
G | 78CDA4DD | 10 | 9DE75E1D
B | A2672345 | 11 | F794B621
W | F7E01F | 12 | F76897
1 | F710EF | FLASH | F7D02F
2 | 6471EC7D | STORBE | F7F00F
3 | 9D52009D | FADE | F7C837
4 | 84044BBD | SMOOTH | F7E817

## تشخیص دود

سنسورهای تشخیص دود و گاز سریMQ ، نسبت به طیف گستردهای از گازها حساساند و در خانه و دمای اتاق قابل استفاده هستند. این سنسورها از هیتر داخلی کوچک و سنسور الکتروشیمیایی برای تشخیص دود و گاز استفاده میکنند. سنسورهایMQ میتوانند کالیبره شوند اما برای این کار، باید غلظت گاز و یا گازها را بدانند ]۱2[.

سنسور گاز 9MQ( شکل ۱۸( که در این پروژه از آن استفاده میشود، دارای حساسیت باال نسبت به کربن مونواکسید، متان و LPG است. این سنسور میتواند برای تشخیص گازهای شامل COو گازهای قابل احتراق به کار رود. جنس مواد حساس این سنسور 2SnO است که رسانایی پایینی در هوای پاک دارد. عملکرد تشخیص این سنسور از طریق باال و پایین رفتن دما است و گاز COرا وقتی که دما پایین میآید شناسایی میکند. رسانایی سنسور با افزایش غلظت گاز زیاد میشود. هنگامی که دما افزایش مییابد این سنسور گاز متان و پروپان و دیگر گازهای قابل اشتعال را تشخیص میدهد و گازهای دیگر جذب شده در دمای کم را رها میکند ]۱2[.

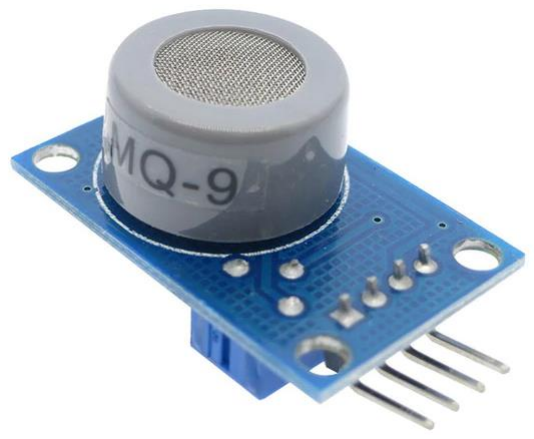
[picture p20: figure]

شکل ۱۸ سنسور تشخیص گازهای سمی -9MQ

## موتور

سرو موتور

به صورت کلی یک الکتروموتور هست که یک سری مدارات الکترونیکی مانند | ۳0
درایوها در کنارآن قرارداردوالکتروموتور حاوی شفت عمل گردش را بهعهدهداردوتجهیزات الکترونیکی هم وظیفه دقت دادن به الکتروموتور را بر عهده دارند و این دقت شامل کنترل زاویه، کنترل شتاب، کنترل سرعت و ... میشود.

سرو موتور ها در انواع گیربکسدار و بدون گیربکس وجود دارند و در اندازه های خیلی کوچک تا اندازههای بزرگ تولید میشوند که اندازههای کوچک در پروژههای رباتیک و تجهیزات مکاترونیکی استفاده شده و اندازههای بزرگ هم در ساخت تجهیزات صنعتی مانند دستگاههای CNC استفاده میشود.

در این پروژه با اضافه کردن یک پروانه به این عملگر، از آن به عنوان سیستم خنک کنندهی محیط استفاده میشود.

۳0 Servo Motor

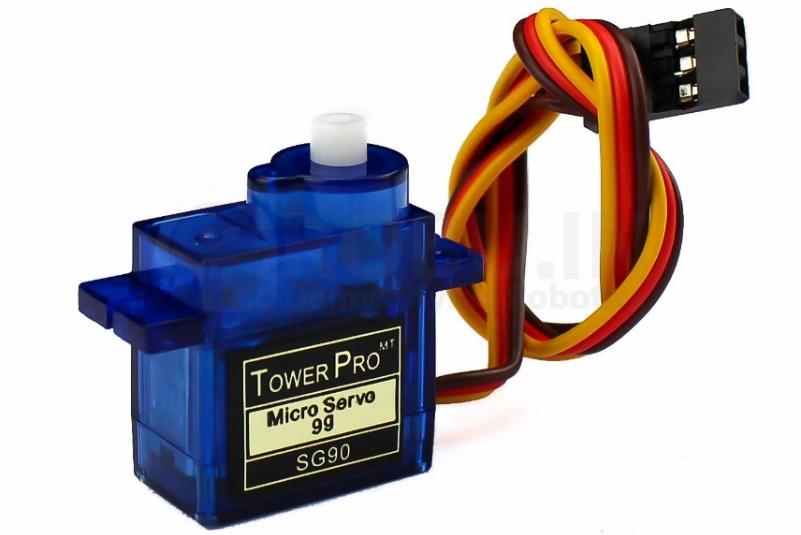
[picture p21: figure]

شکل ۱۹ سرو موتور مدل 90SG

## تشخیص حرکت

از حسگر IR ساخته شدهاند. این حسگرها قابلیت تشخیص حرکت را دارند | ۳۱ | حسگرهای PIR
اما در خصوص نوع حرکت اطالعی نمیدهند.

هر جسمی مقداری گرما از خود متصاعد میکند. حسگر IR موج مادون قرمز ناشی از فرد را دریافت کرده و سیگنال ارسال میکند.

در این پروژه این حسگر در جلوی آینه نصب میشود تا هنگامی که فرد رو به روی آینه قرار گرفت، آینه حضور فرد را تشخیص داده، از حالت نیمه خاموش درآمده و چهرهی فرد مقابل را تشخیص دهد.

۳۱ Passive Infrared

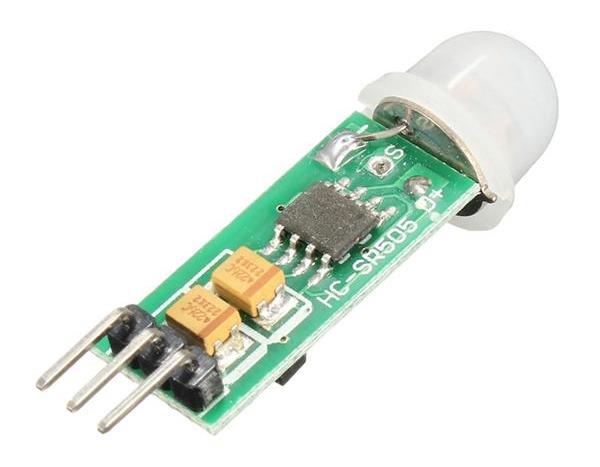
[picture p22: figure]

شکل 20 سنسور حرکت

## MQTT

به طور کلی اینترنت اشیا، همانند اینترنت، دارای یک مدل الیه الیه، است. در شکل ???? میتوان مدل پیشنهادی اینترنت و اینترنت اشیارا در یکتصویرمشاهده نمود. همانطور که در شکل
۳2 | ???? مشاهده میشودیکی از این الیهها،همانند مدل پیشنهادیاینترنت، الیه کاربرد
نام دارد]۱۳[.
یک پروتکل مبتنی بر رویکرد subscribe/publish طراحی گردیده | ۳۳ | پروتکل MQTT
است. این پروتکل در ابتدا به وسیله شرکت IBM توسعه یافت و اکنون یک استاندارد باز میباشد.
، سازگار بودن با تمام دستگاهها و پیاده سازی ساده آن | ۳4 | از مزایای این پروتکل به سبک بودن
میتوان اشاره کرد. این قابلیتها سبب شده است که این پروتکل در موقعیتهای متفاوتی از جمله
۳5 | ارتباط بین دو ماشین

استفاده شود. در ادامه به معرفی بیشتراین پروتکل پرداخته خواهد شد ]۱۳[.

## معماری

معماری ساختار MQTT به صورت server/client است. همان طور که در شکل ????? مشاهده میشود، در این پروتکل تعدادی client با توپولوژی ستارهای به یک server که با نام ۳6 واسط
شناخته میشود در بستر TCP متصل میشوند ]۱۳[.

۳2 Application Layer

۳۳ Message Queuing Telemetry Transport

۳4 Light Weight

۳5 Machine to Machine (M2M)

۳6 Broker

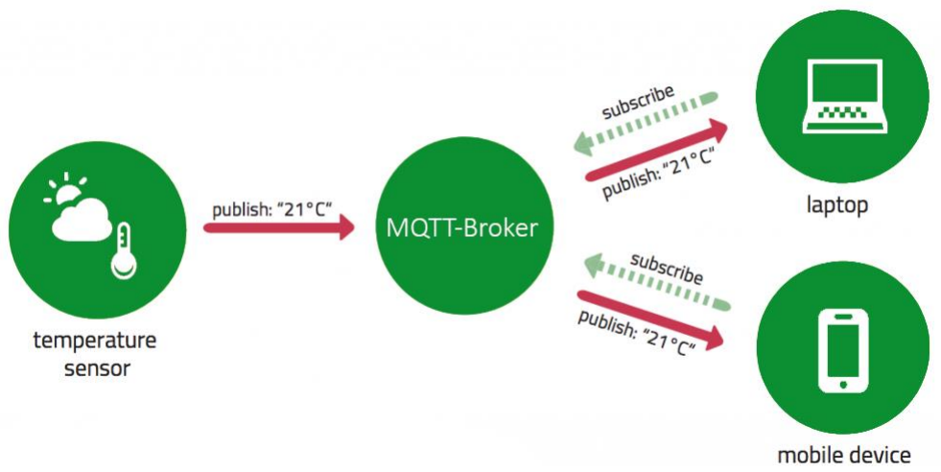
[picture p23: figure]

شکل 2۱ الگوی subscribe/publish در پروتکل MQTT
پروتکل MQTT مبنی بر انتقال پیام است؛ یعنی واسط وظیفهی انتقال پیامها بین client را دارد.
است. واسط با توجه به موضوع پیام ارسال شده، پیام را به تمامی | ۳۷ | هر پیام دارای یک موضوع
clientهایی که این موضوع را دارند )به جز clientفرستندهی پیام( میفرستد. در این پروتکل هر client میتواند پیامهایی با موضاعات متفاوت را بفرستد و دریافت کند. به عنوان نمونه سنسور دما، دمای محیط را با موضوع “temperature “ارسال میکند. واسط پیام را دریافت کرده و به دستگاه
میفرستد. در صورتی که واسط مشترکی | ۳۸ | یا دستگاههایی که با این موضوع اشتراک
با این ۳۹
موضوع پیدا نکند، پیام را ذخیره کرده و به محض متصل شدن یک کالینت با این موضوع، تمامی پیامهای این موضوع را برای client مشترک میفرستد. از آن جایی که این پروتکل حافظهی محدودی دارد، تنها قادر ایت پیامهای اخیر را دخیره کند ]۱۳[.

۳۷ Topic

۳۸ Subscribe

۳۹ Subscriber

## کیفیت خدمات

ارائه میدهد. این سطوح عبارتند از: | 40 | پروتکل MQTT، سه سطح برای کیفیت خدمات

Forget and Fire: این سطح، تنها پیغام مربوطه را ارسال کرده و خود را درگیراین موضوع که آیا گیرنده پیغام را دریافت کردهاست یا خیر، نمیکند.

Once Least at Delivered: در این سطح، سعی میشودتا حداقل یکنمونه از پیغاممربوطه به دست گیرنده برسد.

Once Exactly Delivered: این سطح، همواره یک بسته پیغام را ارسال کرده و منتظر پاسخ ACK آن از سمت گیرنده میشود و سپس بسته بعدی را ارسال میکند. بنابراین با این سازوکار همواره این اطمینان وجود دارد که از هر بسته دقیقا یک نمونه به دست گیرنده میرسد و نیازبه دور ریختن نمونههای اضافهی بستهها نیست ]۱۳[.

## امینت

برای برقراری ملزومات امنیتی، ممکن است واسط از کارخواهان در هنگام برقراری ارتباط، نام کاربری و رمز عبور را درخواست کند. همچنین برای اطمینان از امنیت تبادل اطالعات در این پروتکل ممکن است ارتباط TCP با پروتکل TLS/SSL رمز شود.

40 Quality of Service (QoS)

# بردها

## بدنهی اصلی

دوربین به طور مستقیم با استفاده از کابل فلت به درگاه دوربین متصل میشود.

همچنین Pi Raspberry با استفاده از کابل HDMI به صفحهی نمایشگر پشت آینه متصل میشود.

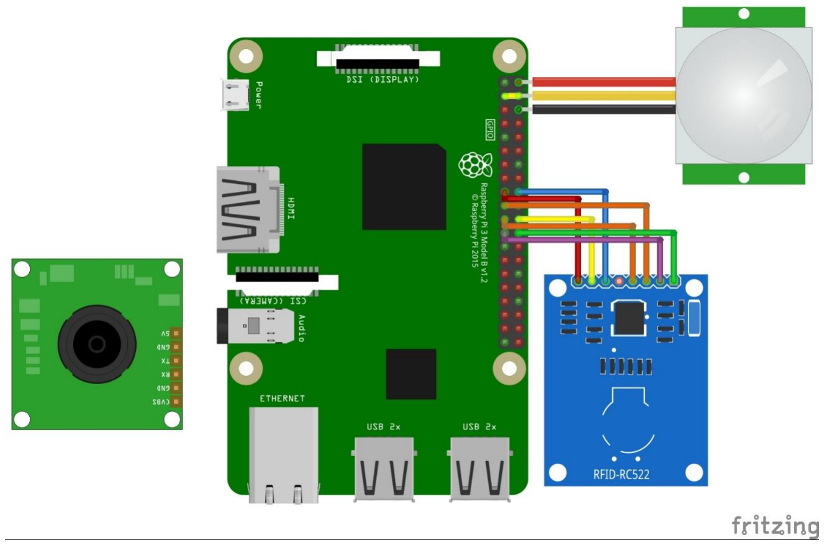
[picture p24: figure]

شکل 22 بخش اصلی طراحی

## مدارهای جانبی

توجه شود که سوئیچهای داخل هر سه مدار به منظور قطع و وصل کردن جریان از منبع میباشد.

همچنین خازنها به منظور حذف نویز بین دو منبع v3.3 و v5 قرار داده شدهاند.

دکمه نیز برای Reset مدار است.

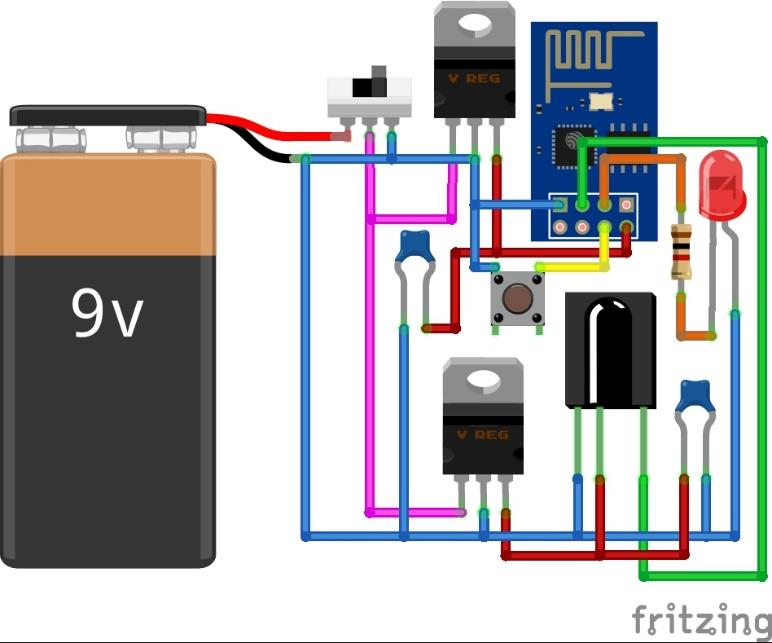
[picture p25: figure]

شکل 2۳ مدار تنظیم روشنایی

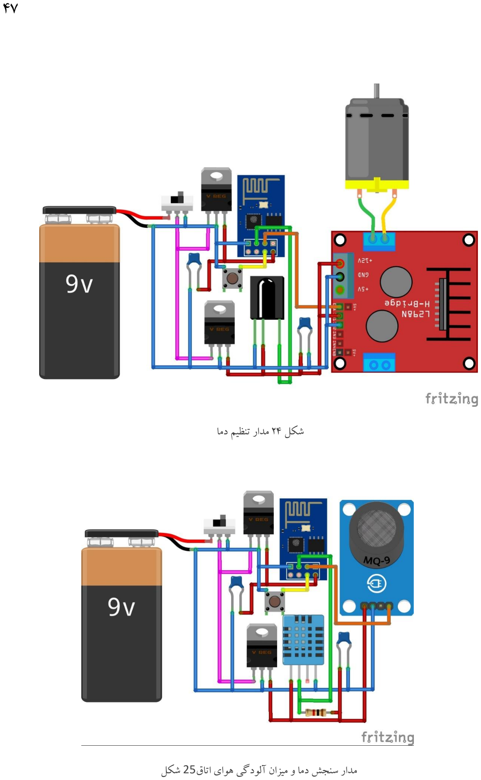
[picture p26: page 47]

شکل 24 مدار تنظیم دما

مدار سنجش دما و میزان آلودگی هوای اتاق25 شکل

# منابع

]1[ | M. Rouse, Internet of Things (IoT), 2019 .
]2[ | C. Yang, W. Shen و X. Wang ,The internet of things in

manufacturing: Key issues and potential applications., 2018 .

]3[ | “Technical | Resource: | Types | and | Applications | of

Microcontrollers,” Engineering Institute of Technolog. Available:

https://www.eit.edu.au/cms/resources/technical-resourses/types-and-applications-of-microcontrollers.

]4[ | R. Jones, A £15 computer to inspire young programmers, BBC
| News, 2011 .
]5[ | S. Bush, Dongle computer lets kids discover programming on a
TV, Electronics Weekly, 2011 .
]6[ | M. Brose, Broadcom BCM2835 SoC has the most powerful
mobile GPU in the world?, Grand MAX, 2012 .
]7[ | “Hardware: Raspberry Pi,” Wikipedia, 2019. Available:

https://en.wikipedia.org/wiki/Raspberry_Pi#Specifications.

]8[ | “Raspberry Pi Pinout“. Available: https://pinout.xyz./

]9[ | “Best operating systems for Raspberry Pi“. Available:
https://raspberrytips.com/best-os-for-raspberry-pi./
]10[ | Philips, “MFRC522 Datasheet,” 22 May 2007. Available:

https://www.elecrow.com/download/MFRC522%20Datasheet.pd f.

]11[ | “DHT11 Humidity & Temperature Sensor Dataheet”. Available:

https://www.mouser.com/ds/2/758/DHT11-Technical-Data-Sheet-Translated-Version-1143054.pdf.

]12[ | H. H. E. Co., “MQ-9 Semiconductor Sensor for CO/Combustible
Gas | Datasheet”,Available:

http://www.haoyuelectronics.com/Attachment/MQ-9/MQ9.pdf.

]13[ | C. Götz, “MQTT 101 – How to Get Started with the lightweight
IoT | Protocol”,Available:

http://www.eclipse.org/community/eclipse_newsletter/2014/october/article2.php.

Sharif University of Tchnology Department of Computer Engineering

B.Sc. Thesis

Implimentation of Smart Room

By:
Fatemeh Abootalebi, Mohammad Amin Isaai

Supervisor:

Dr. Ali Mohammad Afshin Hemmatyar

August 2019

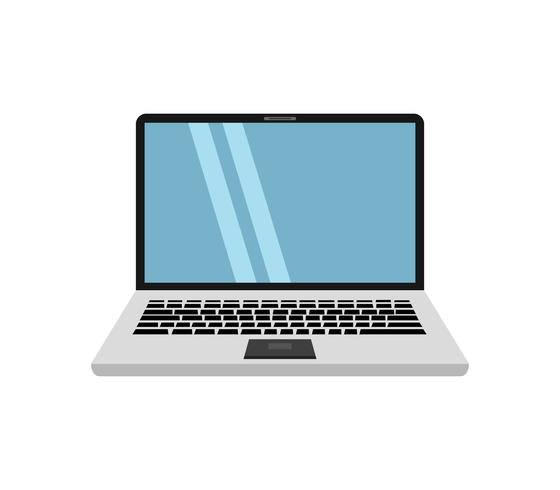
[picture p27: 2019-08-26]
Slide/Pic/Laptop.jpg

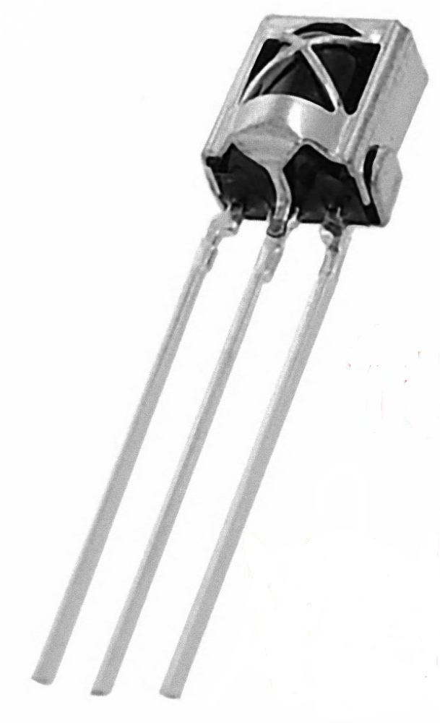
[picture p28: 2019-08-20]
Document/Pic/IR.jpg

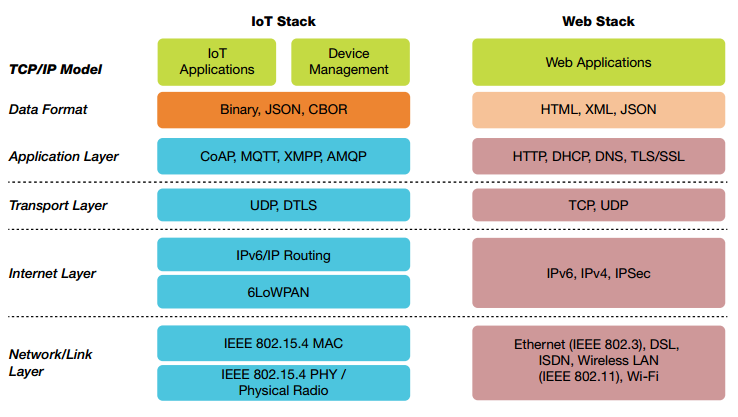
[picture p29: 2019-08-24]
Document/Pic/IoT Web.jpg

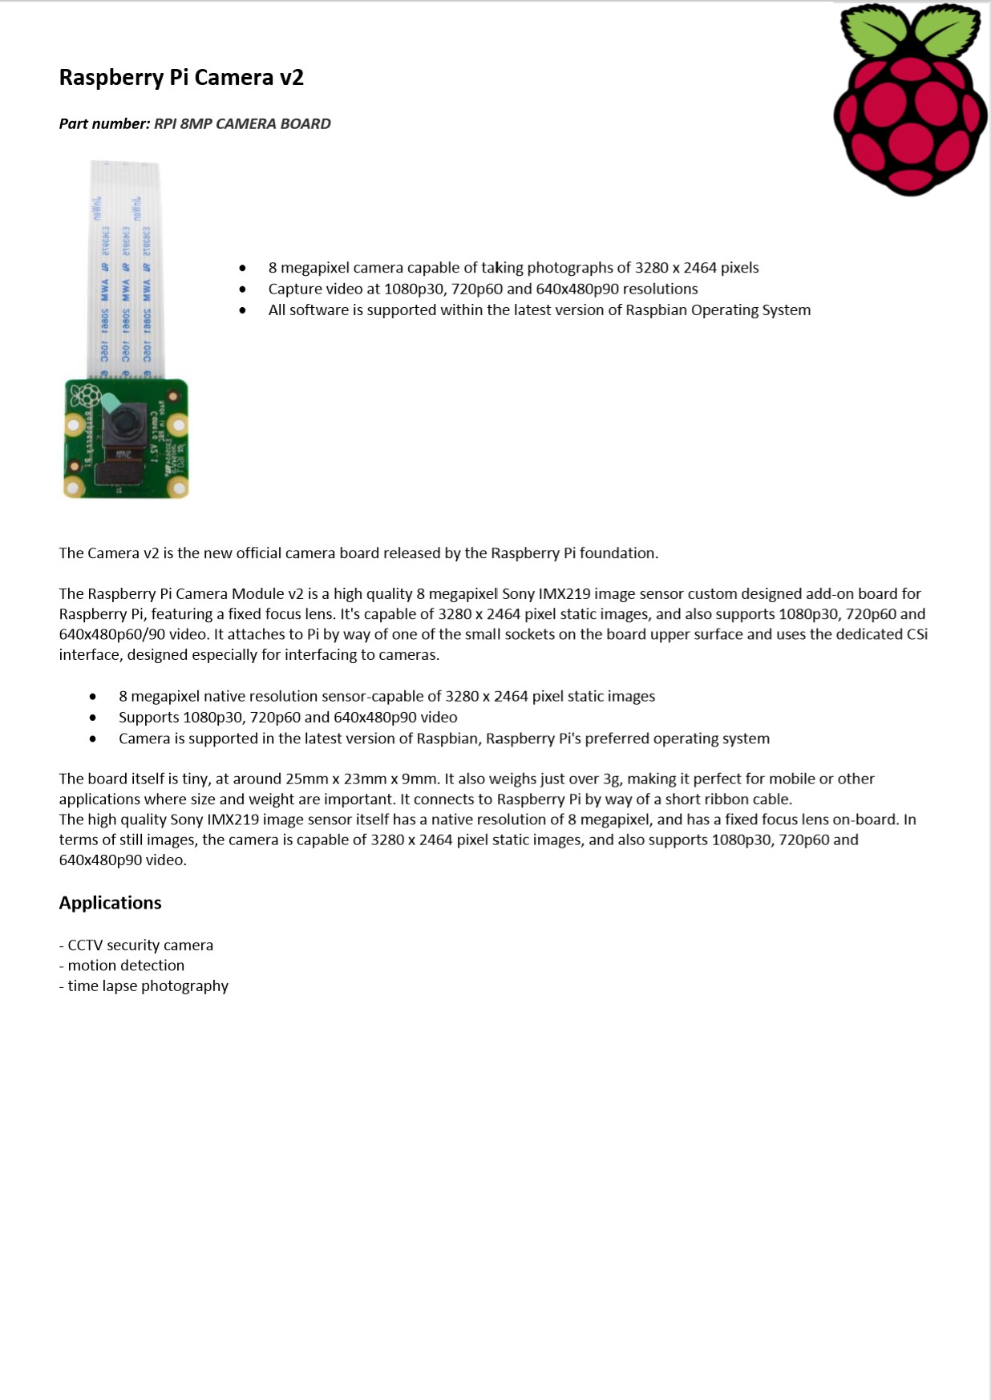
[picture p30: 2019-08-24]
Document/Pic/Camera - Datasheet.jpg

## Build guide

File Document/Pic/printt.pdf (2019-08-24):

عنوان: گسترش چارچوب تحویل منضبط چابک با استفاده از رویکرد مدلرانه

نگارش: مهدیس تاجداری

استاد راهنما: دكتر رامان رامسين

سال اجرا: ۱۳۹۸

نام استاد پروژه:

محل امضا: تاریخ:

نمره پروژه به عدد:

نمره پروژه به حروف:

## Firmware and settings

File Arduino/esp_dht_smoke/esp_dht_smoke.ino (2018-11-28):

//ESP 3 with DHT & Smoke

#include <ESP8266WiFi.h>
#include "Adafruit_MQTT.h"
#include "Adafruit_MQTT_Client.h"
#include "DHT.h"

/************************* WiFi Access Point *********************************/
#define WLAN_SSID       "Smart Lab"
#define WLAN_PASS       "amints25"

#define MQTT_SERVER      "192.168.43.101" // ip address of rpi
#define MQTT_PORT         1883
#define MQTT_USERNAME    ""
#define MQTT_PASSWORD         ""



//
/************ Global State ******************/
#define DHT_PIN      2              // Pin connected to the IR. GPIO 0
#define LAMP    0              // Pin connected to the lamp. GPIO 2 
#define DHT_TYPE DHT11  // for DHT model == DHT 11


// Create an ESP8266 WiFiClient class to connect to the MQTT server.
WiFiClient client;
// Setup the MQTT client class by passing in the WiFi client and MQTT server and login details.
Adafruit_MQTT_Client mqtt(&client, MQTT_SERVER, MQTT_PORT, MQTT_USERNAME, MQTT_PASSWORD);
/****************************** Feeds ***************************************/
// Setup a feeds for publishing.

// Notice MQTT paths for AIO follow the form: <username>/feeds/<feedname>
Adafruit_MQTT_Publish pi_mqtt_led = Adafruit_MQTT_Publish(&mqtt, MQTT_USERNAME "/pi/mqtt led");         //checking mqtt connection for rpi
Adafruit_MQTT_Publish pi_lcd = Adafruit_MQTT_Publish(&mqtt, MQTT_USERNAME "/pi/lcd");                   //give rpi messages for printing
Adafruit_MQTT_Publish pi_notif = Adafruit_MQTT_Publish(&mqtt, MQTT_USERNAME "/pi/notif");               //give rpi notifications
Adafruit_MQTT_Publish pi_dht = Adafruit_MQTT_Publish(&mqtt, MQTT_USERNAME "/pi/dht");               //give rpi notifications
Adafruit_MQTT_Publish pi_notif = Adafruit_MQTT_Publish(&mqtt, MQTT_USERNAME "/pi/smoke");               //give rpi notifications

// Setup a feed for subscribing to changes.
Adafruit_MQTT_Subscribe esp_dht = Adafruit_MQTT_Subscribe(&mqtt, MQTT_USERNAME "/esp3/dht");            // get messages for dht
Adafruit_MQTT_Subscribe esp_smoke = Adafruit_MQTT_Subscribe(&mqtt, MQTT_USERNAME "/esp3/smoke");        // get messages for Lamp

/*************************** Sketch Code ************************************/

uint32_t x = 0;

int timer = 0;

void MQTT_connect();

//DHT
DHT dht(DHT_PIN, DHT_TYPE);
String sh;
String st;
String dht_string = "Nothing stored untill now!";

//Smoke
int sensorValue;
float sensor_volt;
float RS_gas; // Get value of RS in a GAS
float ratio; // Get ratio RS_GAS/RS_air
String smoke_string;


void setup() {
  Serial.begin(115200);

  Serial.println(F("RPi-ESP3-MQTT"));
  
  // Connect to WiFi access point.
  Serial.println(); Serial.println();
  Serial.print("Connecting to ");
  Serial.println(WLAN_SSID);
  WiFi.begin(WLAN_SSID, WLAN_PASS);
  while (WiFi.status() != WL_CONNECTED) {
    delay(500);
    Serial.print(".");
  }
  Serial.println();
  Serial.println("WiFi connected");
  Serial.println("IP address: "); Serial.println(WiFi.localIP());

  // Setup MQTT subscription for feeds.
  mqtt.subscribe(&esp_smoke);
  mqtt.subscribe(&esp_dht);

  //Start DHT
  dht.begin();
}

void loop() {
  
  /* Ensure the connection to the MQTT server is alive (this will make the first
  connection and automatically reconnect when disconnected).  See the MQTT_connect*/
  MQTT_connect();
  /* this is our 'wait for incoming subscription packets' busy subloop try to spend your time here*/

  /************* DHT code: *************/
  // Reading temperature or humidity takes about 250 milliseconds!
  // Sensor readings may also be up to 2 seconds 'old' (its a very slow sensor)
  float h = dht.readHumidity();
  // Read temperature as Celsius (the default)
  float temp = dht.readTemperature();

  if (isnan(h) || isnan(temp)) {
    Serial.println("Failed to read from DHT sensor!");
  } else {

    st = String(temp);
    sh = String(h);
    dht_string = "Humidity: " + sh + " %\t" + "Temperature: " + st + " *C";
    //Serial.println(dht_string);
  }

  /************* Smoke code: *************/
  sensorValue = analogRead(A0);
  sensor_volt = (float)sensorValue / 1024 * 5.0;
  RS_gas = (5.0 - sensor_volt) / sensor_volt; // omit *RL

  //-0.09 was the value of R0 from the mq9 tester file
  ratio = RS_gas / -0.09; // ratio = RS/R0
  /*-----------------------------------------------------------------------*/
  smoke_string = "sensor_volt= " + String(sensor_volt) + "RS_ratio= "   + String(ratio);
  //Serial.println(smoke_string);


  /**************** MQTT subscription code: ****************/
  // Here its read the subscription
  Adafruit_MQTT_Subscribe *subscription;
  while ((subscription = mqtt.readSubscription())) {
    if (subscription == &esp_smoke) {
      char *message = (char *)esp_smoke.lastread;
      Serial.print(F("Got: "));
      Serial.println(message);
      // Check if the message feedback.
      if (strncmp(message, "feedback", 8) == 0) {
        pi_notif.publish("esp_dht_smoke is sending Smoke response...");
        char smoke_char_array[smoke_string.length() + 1];
        smoke_string.toCharArray(smoke_char_array, smoke_string.length() + 1 );
        pi_smoke.publish(smoke_char_array);
      }
    }

    else if (subscription == &esp_dht) {
      char *message = (char *)esp_dht.lastread;
      Serial.print(F("Got: "));
      Serial.println(message);
      // Check if the message was for feedback
      if (strncmp(message, "feedback", 8) == 0) {
        pi_notif.publish("esp_dht_smoke is sending dht response...");
        char dht_char_array[dht_string.length() + 1];
        dht_string.toCharArray(dht_char_array, dht_string.length() + 1 );
        pi_dht.publish(dht_char_array);
      }
    }
  }
  //Wait for 2 seconds before starting another temp and smoke getting
  delay(2000);
  
  timer += 1;
  // each (t * 2) seconds sends feedback automatically
  int t = 5;
  if (timer % t == 0) {
    char dht_char_array[dht_string.length() + 1];
    dht_string.toCharArray(dht_char_array, dht_string.length() + 1 );
    pi_dht.publish(dht_char_array);

    char smoke_char_array[smoke_string.length() + 1];
    smoke_string.toCharArray(smoke_char_array, smoke_string.length() + 1 );
    pi_smoke.publish(smoke_char_array);
  }
}



void MQTT_connect() {
  int8_t ret;
  // Stop if already connected.
  if (mqtt.connected()) {
    return;
  }
  Serial.print("Connecting to MQTT... ");
  uint8_t retries = 3;
  while ((ret = mqtt.connect()) != 0) { // connect will return 0 for connected
    Serial.println(mqtt.connectErrorString(ret));
    Serial.println("Retrying MQTT connection in 5 seconds...");
    mqtt.disconnect();
    delay(5000);  // wait 5 seconds
    retries--;
    if (retries == 0) {
      // basically die and wait for WDT to reset me
      while (1);
    }
  }
  Serial.println("MQTT Connected!");
}

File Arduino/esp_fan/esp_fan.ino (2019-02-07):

//ESP 1 with Fan & IR

#include <ESP8266WiFi.h>
#include <IRremoteESP8266.h>
#include <IRrecv.h>
#include <IRutils.h>
#include "Adafruit_MQTT.h"
#include "Adafruit_MQTT_Client.h"
/************************* WiFi Access Point *********************************/
#define WLAN_SSID       "Smart Lab"
#define WLAN_PASS       "amints25"

#define MQTT_SERVER      "192.168.0.100" // ip address of rpi
#define MQTT_PORT         1883
#define MQTT_USERNAME    ""
#define MQTT_PASSWORD         ""



//
/************ Global State ******************/
#define IR            2              // Pin connected to the IR. GPIO 2
#define FAN_SPEED     0              // Pin connected to the Fan and sets speed of the fan. GPIO 0



// Create an ESP8266 WiFiClient class to connect to the MQTT server.
WiFiClient client;
// Setup the MQTT client class by passing in the WiFi client and MQTT server and login details.
Adafruit_MQTT_Client mqtt(&client, MQTT_SERVER, MQTT_PORT, MQTT_USERNAME, MQTT_PASSWORD);
/****************************** Feeds ***************************************/
// Setup a feeds for publishing.

// Notice MQTT paths for AIO follow the form: <username>/feeds/<feedname>
Adafruit_MQTT_Publish pi_lcd = Adafruit_MQTT_Publish(&mqtt, MQTT_USERNAME "/pi/lcd");             //give rpi messages for printing
Adafruit_MQTT_Publish pi_ir = Adafruit_MQTT_Publish(&mqtt, MQTT_USERNAME "/pi/ir");               // publish ir commands for rpi to handle
Adafruit_MQTT_Publish pi_notif = Adafruit_MQTT_Publish(&mqtt, MQTT_USERNAME "/pi/notif");         //give rpi notifications

// Setup a feed for subscribing to changes.
Adafruit_MQTT_Subscribe esp_fan = Adafruit_MQTT_Subscribe(&mqtt, MQTT_USERNAME "/esp1/fan");        // get messages for Fan
/*************************** Sketch Code ************************************/

void set_fan_state(int state);

void MQTT_connect();

//IR setup
IRrecv irrecv(IR);
decode_results results;


void setup() {
  Serial.begin(115200);

  // set IR 
  irrecv.enableIRIn();  // Start the receiver

  //Set FanSpeed pin
  pinMode(FAN_SPEED, OUTPUT);

  Serial.println(F("RPi-ESP1-MQTT"));
  // Connect to WiFi access point.
  Serial.println(); Serial.println();
  Serial.print("Connecting to ");
  Serial.println(WLAN_SSID);
  WiFi.begin(WLAN_SSID, WLAN_PASS);
  while (WiFi.status() != WL_CONNECTED) {
    delay(500);
    Serial.print(".");
  }
  
  Serial.println();
  Serial.println("WiFi connected");
  Serial.println("IP address: "); Serial.println(WiFi.localIP());
  pi_notif.publish("esp_fan WIFI connected.");
  
  // Setup MQTT subscription for feeds.
  mqtt.subscribe(&esp_fan);
}

void loop() {

  //********************  TODO set mqtt feedback for rpi  ***************************
  /* Ensure the connection to the MQTT server is alive (this will make the first
   connection and automatically reconnect when disconnected).  See the MQTT_connect*/
  MQTT_connect();
  // this is our 'wait for incoming subscription packets' busy subloop


  // check for IR response
  if (irrecv.decode(&results)) {
    unsigned int value = results.value;
    pi_ir.publish(value);//send ir received value to rpi
    pi_notif.publish("esp_fan sent IR" + value);//send ir received value to rpi
    irrecv.resume(); // Receive the next value
  }


  // Here its read the subscription
  Adafruit_MQTT_Subscribe *subscription;
  while ((subscription = mqtt.readSubscription())) {
    if (subscription == &esp_fan) {
      char *message = (char *)esp_fan.lastread;
      Serial.print(F("Got: "));
      Serial.println(message);
      
      // Check if the message was off, low, medium or high.
      if (strncmp(message, "off", 3) == 0) {
        // Turn the fan off
        set_fan_state(0);
      }
      
      else if (strncmp(message, "low", 3) == 0) {
        // Turn the fan to low speed
        set_fan_state(1);
      }
      
      else if (strncmp(message, "medium", 6) == 0) {
        // Turn the fan to medium speed
        set_fan_state(2);
      }
      
      else if (strncmp(message, "high", 4) == 0) {
        // Turn the fan to high speed
        set_fan_state(3);
      }
    }
  }


}
// Function to connect and reconnect as necessary to the MQTT server.

void MQTT_connect() {
  int8_t ret;
  // Stop if already connected.
  if (mqtt.connected()) {
    return;
  }
  Serial.print("Connecting to MQTT... ");
  uint8_t retries = 3;
  while ((ret = mqtt.connect()) != 0) { // connect will return 0 for connected
    Serial.println(mqtt.connectErrorString(ret));
    Serial.println("Retrying MQTT connection in 5 seconds...");
    mqtt.disconnect();
    delay(5000);  // wait 5 seconds
    retries--;
    if (retries == 0) {
      // basically die and wait for WDT to reset me
      while (1);
    }
       pi_notif.publish("ESP1 MQTT connected.");
  }
}
//function for setting speed of fan
void set_fan_state(int state) {
  if (state == 0) {
    analogWrite(FAN_SPEED, 0); // Send PWM signal to L298N FAN_SPEED pin
    pi_notif.publish("fan turned OFF");
  }
  
  else if (state == 1) {
    analogWrite(FAN_SPEED, 130); // Send PWM signal to L298N FAN_SPEED pin
    pi_notif.publish("esp_fan turned LOW");
  }
  
  else if (state == 2) {
    analogWrite(FAN_SPEED, 185); // Send PWM signal to L298N FAN_SPEED pin
    pi_notif.publish("esp_fan turned MEDIUM");
  }
  
  else if (state == 3) {
    analogWrite(FAN_SPEED, 255); // Send PWM signal to L298N FAN_SPEED pin
    pi_notif.publish("esp_fan turned HIGH");
  }
}

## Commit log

2018-09-11 Arduino files added
2018-10-15 arduino update
2018-10-15 esp arduino IR code bug fixes
    [esp_fan.ino, esp_lamp.ino]
2018-10-17 IR pin changed to 2 in
2018-10-17 DHT pin changed to 2
2018-10-18 prints cleaning
2018-10-18 esp fan bug fixes
    [esp_fan.ino]
2018-10-18 fan syntax bug fixes
    [esp_fan.ino]
2018-10-18 fan test
2019-02-07 arduino code edited
2019-08-24 fritzing files added
    [Fan.fzz, IR Decoder.fzz, Lamp.fzz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]
